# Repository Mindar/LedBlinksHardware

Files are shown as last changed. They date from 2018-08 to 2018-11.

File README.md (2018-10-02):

# LedBlinks
LedBlinks is a wifi configurable controller/driver for up to 3 independent channels. It can be used to control RGB LED strips over wifi. But you can control any other load, for example three independent white led strips or just 3 single leds.

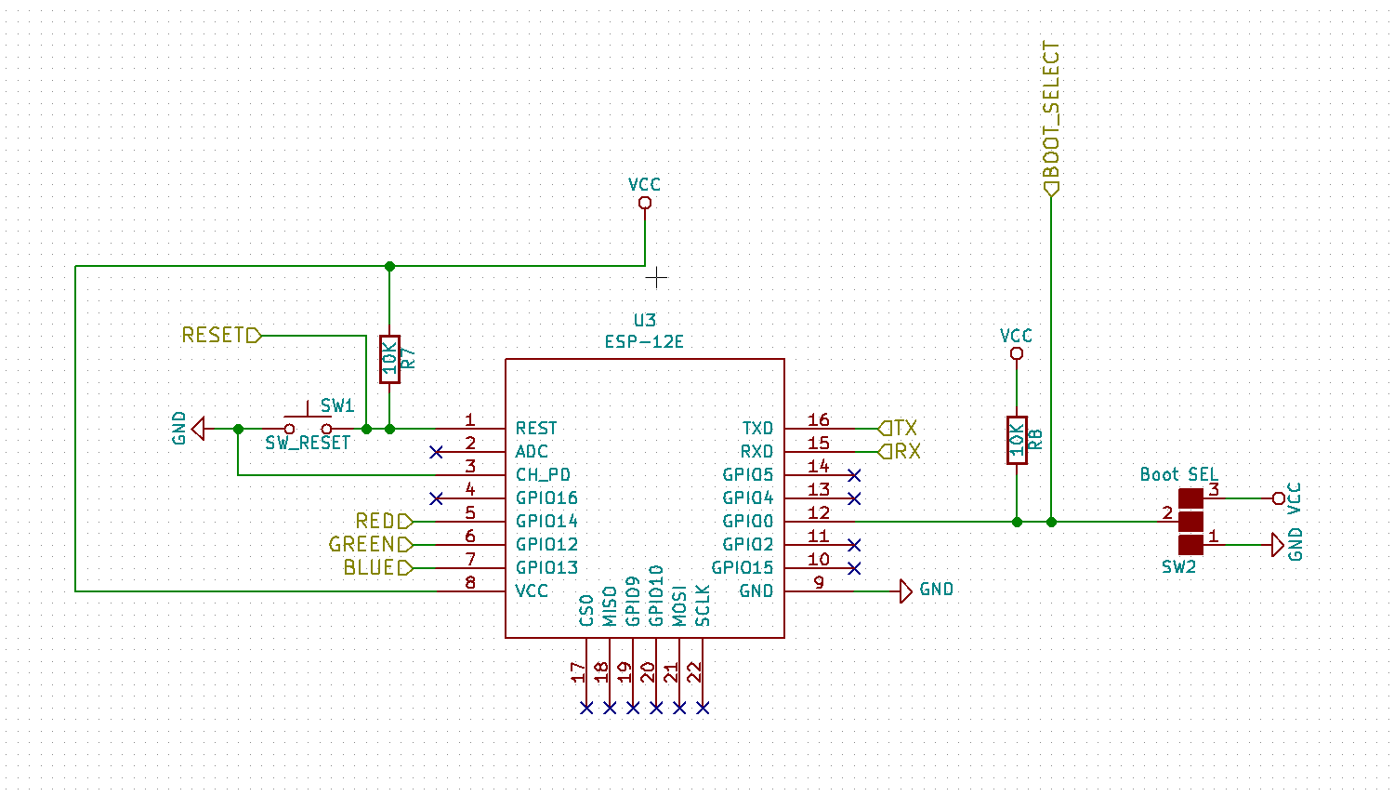
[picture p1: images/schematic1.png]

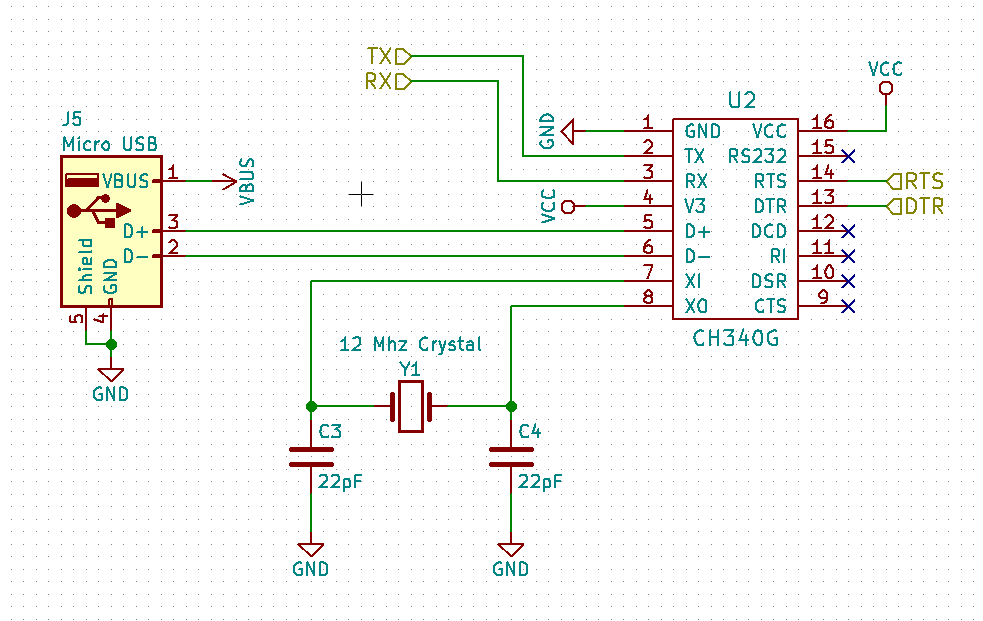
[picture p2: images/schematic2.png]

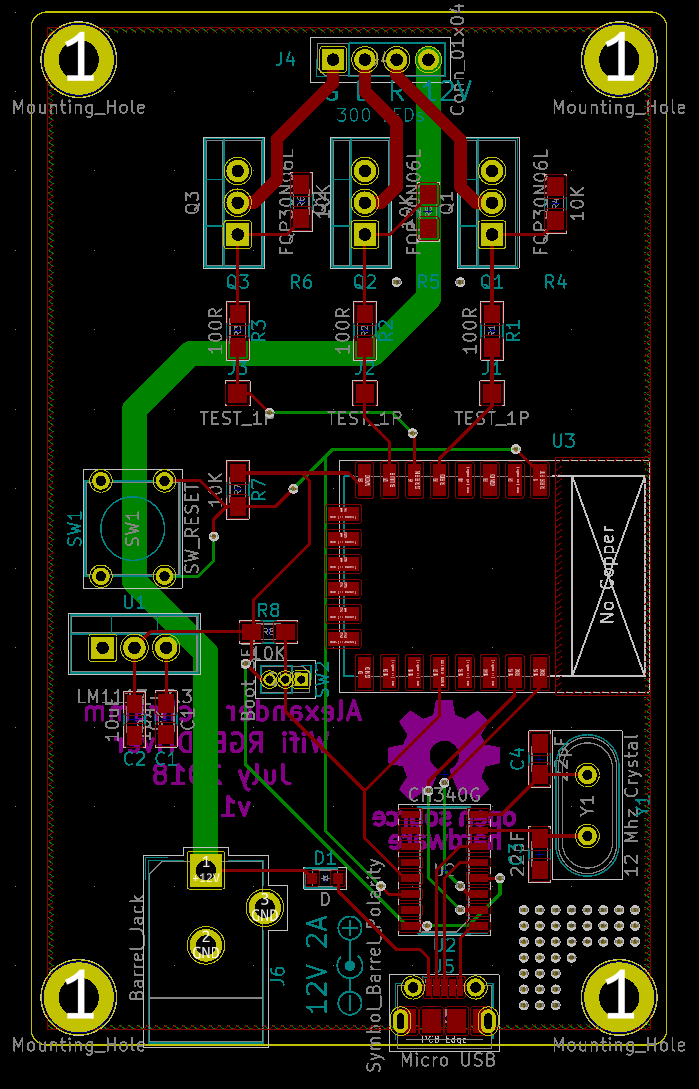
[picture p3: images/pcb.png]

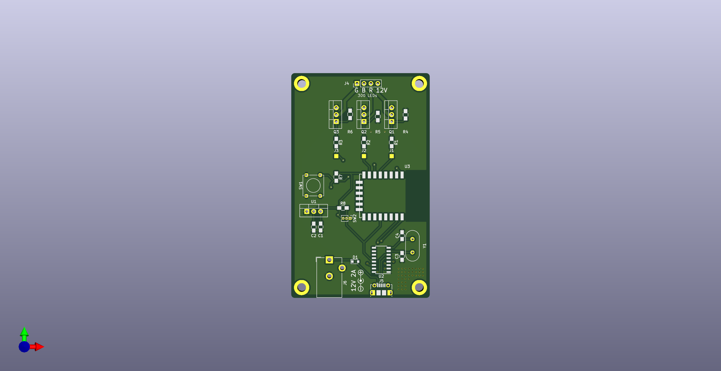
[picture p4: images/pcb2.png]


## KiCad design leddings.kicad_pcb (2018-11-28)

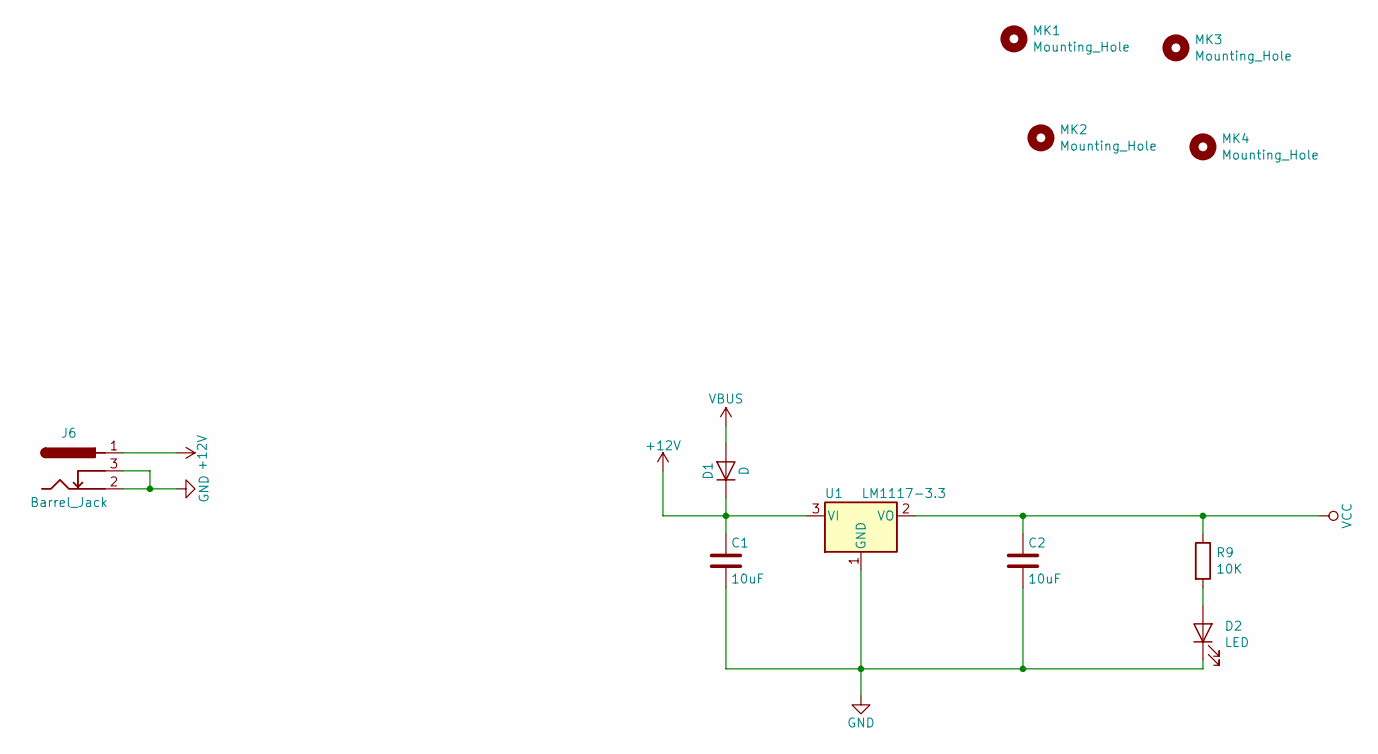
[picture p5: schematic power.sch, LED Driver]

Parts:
C1, C2: 10uF; C_0805_HandSoldering
D1: D; D_SOD-123F
D2: LED; LED_0805_HandSoldering
J6: Barrel_Jack; Barrel_Jack_CUI_PJ-102AH
MK1, MK2, MK3, MK4: Mounting_Hole; MountingHole_3.2mm_M3_DIN965_Pad
R9: 10K; R_0805_HandSoldering
U1: LM1117-3.3; TO-252-2

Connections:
+12V: C1.1, D1.1 (K), J6.1, U1.3 (VI); also elsewhere on the board
GND: C1.2, C2.2, D2.1 (K), J6.2, J6.3, U1.1 (GND); also elsewhere on the board
unnamed: D2.2 (A), R9.2
VBUS: D1.2 (A); also elsewhere on the board
VCC: C2.1, R9.1, U1.2 (VO); also elsewhere on the board

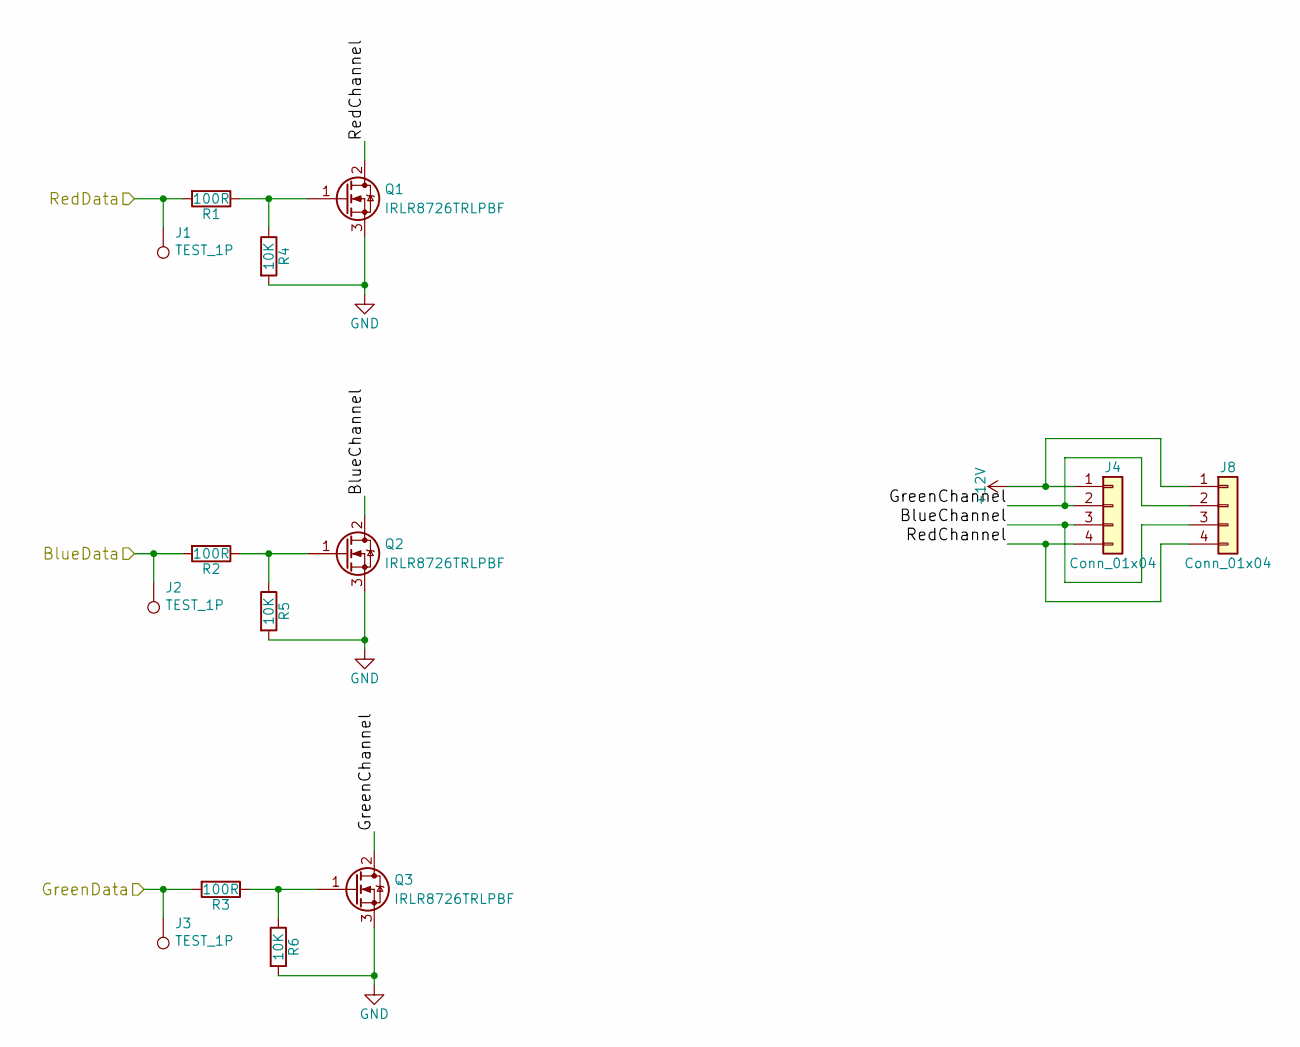
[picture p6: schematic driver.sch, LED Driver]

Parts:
J1, J2, J3: TEST_1P; Measurement_Point_Square-SMD-Pad_Small
J4: Conn_01x04; TerminalBlock_bornier-4_P5.08mm
J8: Conn_01x04; PinHeader_1x04_P2.54mm_Vertical
Q1, Q2, Q3: IRLR8726TRLPBF; TO-252-2
R1, R2, R3: 100R; R_0805_HandSoldering
R4, R5, R6: 10K; R_0805_HandSoldering

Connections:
+12V: J4.1, J8.1; also elsewhere on the board
/Controller/BLUE: J2.1, R2.2; also elsewhere on the board
/Controller/GREEN: J3.1, R3.2; also elsewhere on the board
/Controller/RED: J1.1, R1.2; also elsewhere on the board
/LED Driver/BlueChannel: J4.3, J8.3, Q2.2 (D)
/LED Driver/GreenChannel: J4.2, J8.2, Q3.2 (D)
/LED Driver/RedChannel: J4.4, J8.4, Q1.2 (D)
GND: Q1.3 (S), Q2.3 (S), Q3.3 (S), R4.2, R5.2, R6.2; also elsewhere on the board
unnamed: Q1.1 (G), R1.1, R4.1
unnamed: Q2.1 (G), R2.1, R5.1
unnamed: Q3.1 (G), R3.1, R6.1

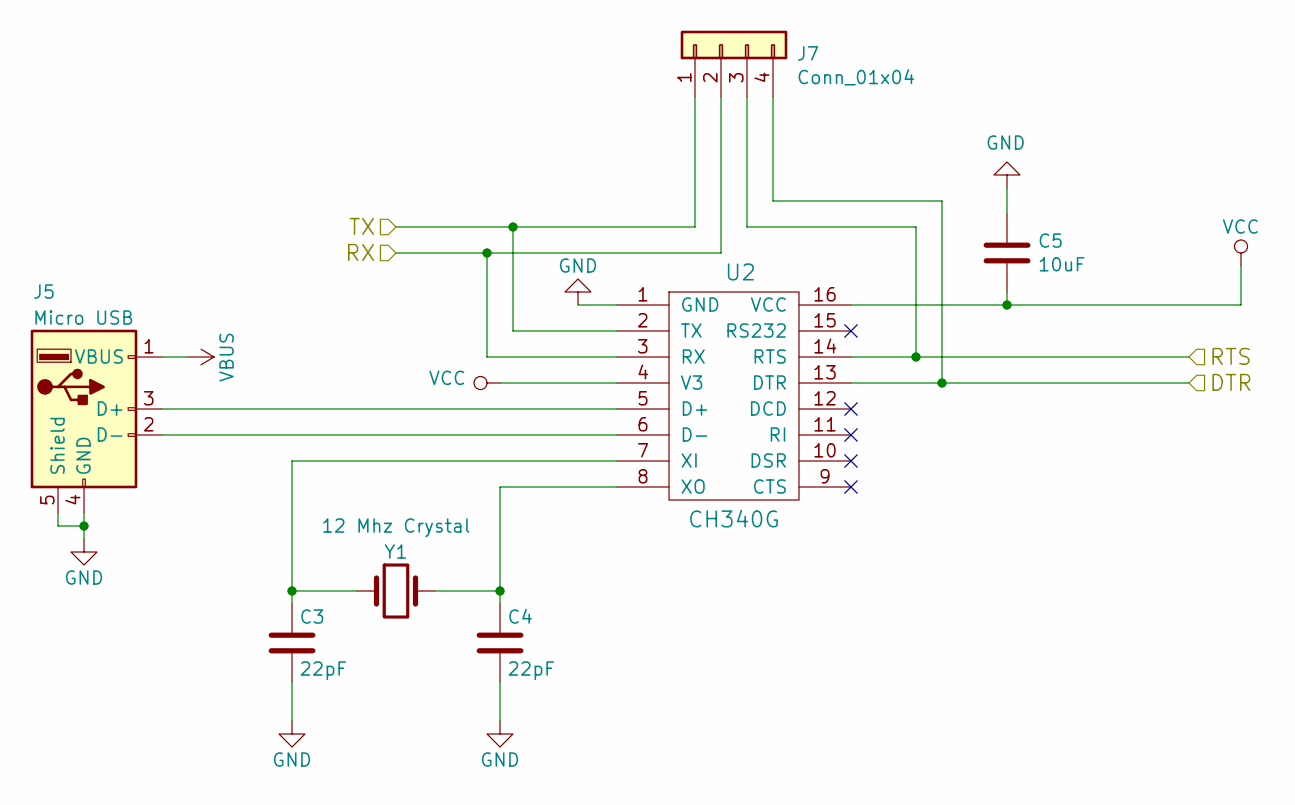
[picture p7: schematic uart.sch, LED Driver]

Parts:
C3, C4: 22pF; C_0805_HandSoldering
C5: 10uF; C_0805_2012Metric_Pad1.15x1.40mm_HandSolder
J5: Micro USB; USB_Micro-B_Molex-105017-0001
J7: Conn_01x04; Pin_Header_Straight_1x04_Pitch2.54mm
U2: CH340G; SOIC-16_3.9x9.9mm_Pitch1.27mm
Y1: 12 Mhz Crystal; Crystal_HC49-U_Vertical

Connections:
/Controller/BOOT_SELECT: J7.4, U2.13 (DTR); also elsewhere on the board
/Controller/RESET: J7.3, U2.14 (RTS); also elsewhere on the board
/Controller/RX: J7.1, U2.2 (TX); also elsewhere on the board
/USB UART Interface/RX: J7.2, U2.3 (RX); also elsewhere on the board
GND: C3.2, C4.2, C5.1, J5.4 (GND), J5.5 (Shield), J5.6, U2.1 (GND); also elsewhere on the board
unnamed: C3.1, U2.7 (XI), Y1.1
unnamed: C4.1, U2.8 (XO), Y1.2
unnamed: J5.2 (D-), U2.6 (D-)
unnamed: J5.3 (D+), U2.5 (D+)
VBUS: J5.1 (VBUS); also elsewhere on the board
VCC: C5.2, U2.4 (V3), U2.16 (VCC); also elsewhere on the board

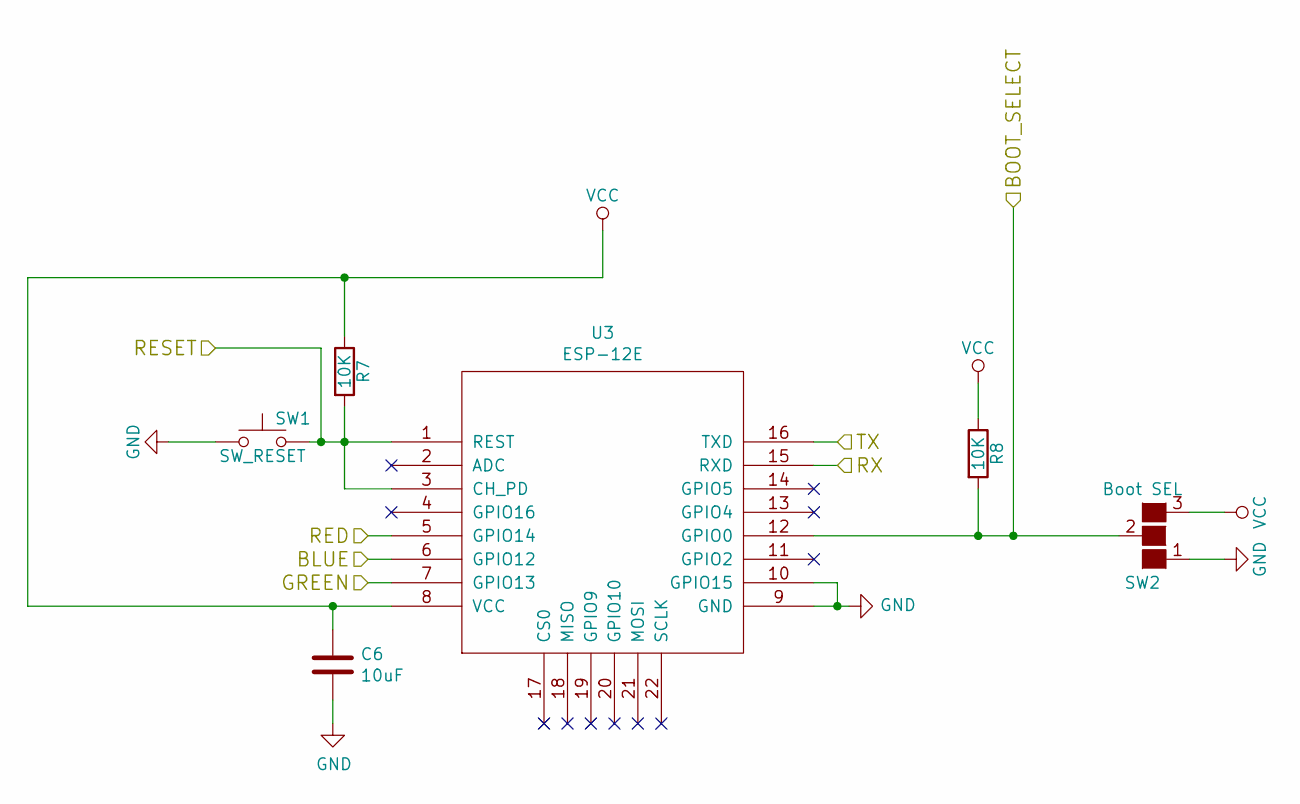
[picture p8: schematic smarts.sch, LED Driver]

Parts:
C6: 10uF; R_0805_2012Metric_Pad1.15x1.40mm_HandSolder
R7, R8: 10K; R_0805_HandSoldering
SW1: SW_RESET; SW_SPST_B3S-1000
SW2: Boot SEL; Pin_Header_Straight_1x03_Pitch2.54mm
U3: ESP-12E; ESP-12E_SMD

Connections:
/Controller/BLUE: U3.6 (GPIO12); also elsewhere on the board
/Controller/BOOT_SELECT: R8.2, SW2.2 (G2), U3.12 (GPIO0); also elsewhere on the board
/Controller/GREEN: U3.7 (GPIO13); also elsewhere on the board
/Controller/RED: U3.5 (GPIO14); also elsewhere on the board
/Controller/RESET: R7.2, SW1.2, U3.1 (REST), U3.3 (CH_PD); also elsewhere on the board
/Controller/RX: U3.15 (RXD); also elsewhere on the board
/USB UART Interface/RX: U3.16 (TXD); also elsewhere on the board
GND: C6.2, SW1.1, SW2.1 (G1), U3.9 (GND), U3.10 (GPIO15); also elsewhere on the board
VCC: C6.1, R7.1, R8.1, SW2.3 (G3), U3.8 (VCC); also elsewhere on the board

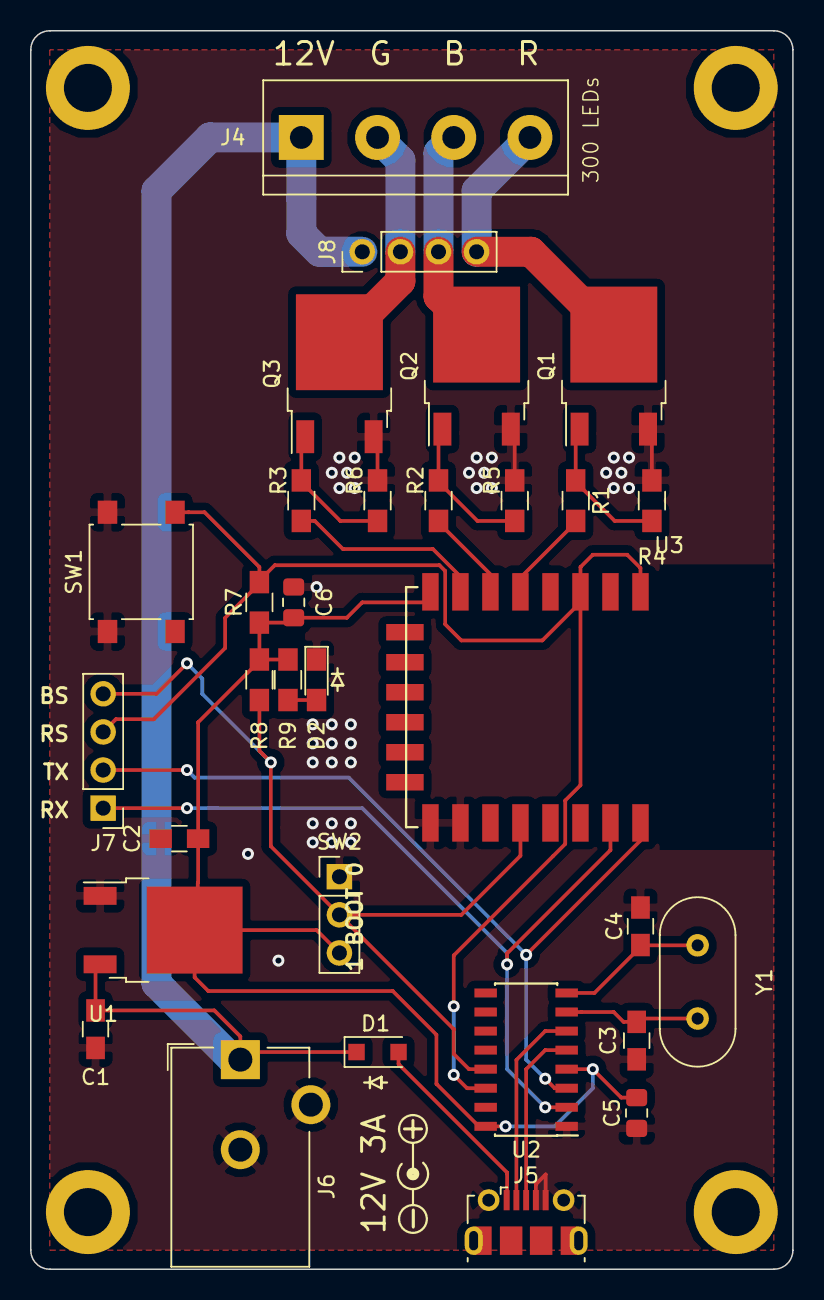
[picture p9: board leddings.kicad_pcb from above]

Board: 2 copper layers, 50.8 x 82.6 mm, 35 parts (0 on the bottom side), 22 nets.

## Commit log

2018-06-07 added stuff
    [driver.sch, leddings.kicad_pcb, power.sch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]
2018-08-01 Did a stuff
    [driver-2018-07-18-23-33-33.sch, driver.sch, leddings-2018-07-18-23-33-33.sch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]
2018-10-02 added pin headers for uart, added power-on-led, improved routing
    [driver.sch, leddings.kicad_pcb, leddings.sch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]
2018-11-23 changed some parts to smd, fixed some design errors
    [_saved_smarts.sch, driver.sch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]
2018-11-28 changed text on pcb
    [_saved_smarts.sch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]
